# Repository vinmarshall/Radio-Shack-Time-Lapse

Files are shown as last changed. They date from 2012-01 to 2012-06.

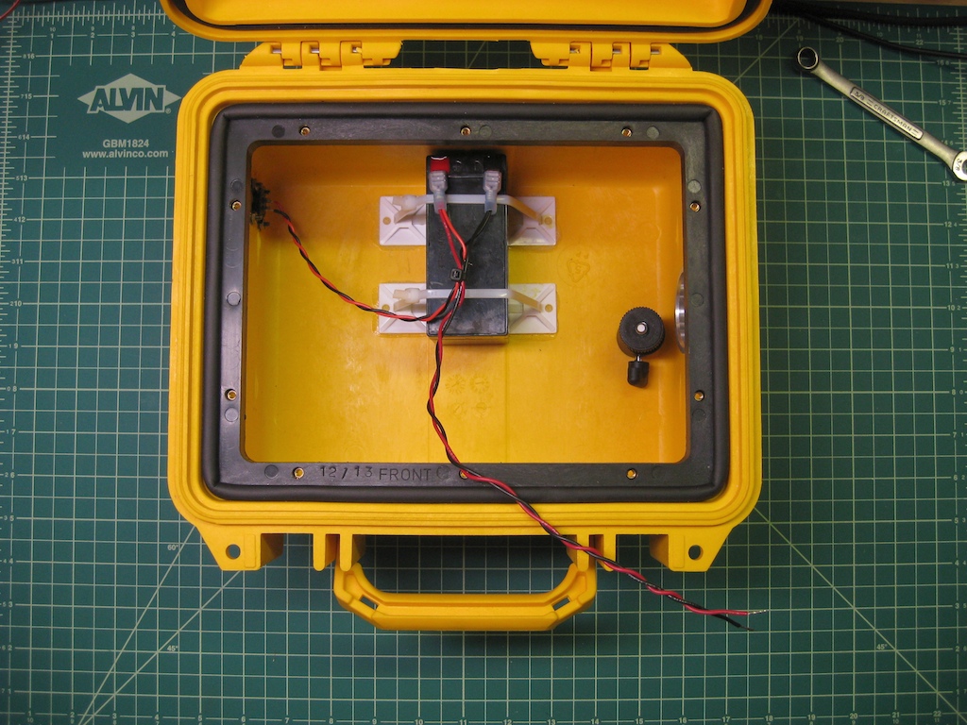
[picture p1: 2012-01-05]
images/wiring/battery_1.jpg

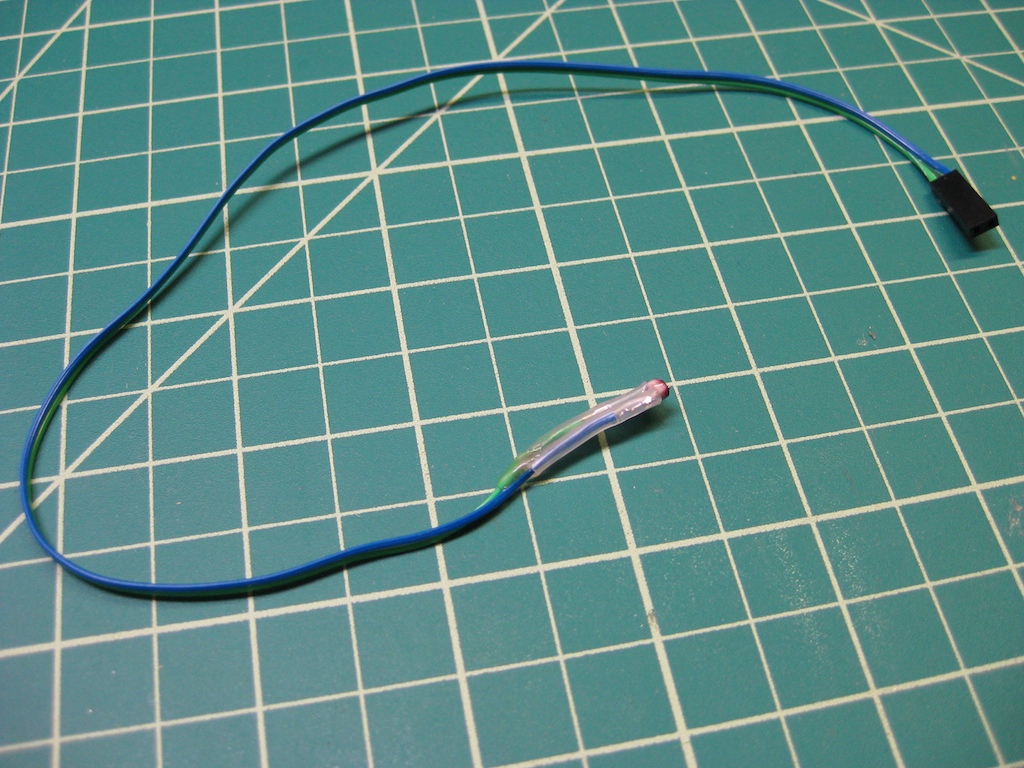
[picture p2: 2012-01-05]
images/wiring/daylight_sensor_1.jpg

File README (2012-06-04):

These files are the plans for the "Rugged Outdoor Time Lapse" project
that was featured in the September 2011 issue of Popular Science.  Look 
at the instructions file for more information.

./front_panel - Files for making the control panel.

./images - Pictures of details of building the project.

./PCB - Circuit schematic and board layout.  Express PCB files plus
  images of the trace layers and mechanical drawings of the board.

./parts - Bill of Materials and parts sourcing information

./schematic - The schematic for the circuit

./time_lapse_code - Arduino code

instructions - Instructions for building this project

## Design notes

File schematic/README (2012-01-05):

The files in this directory are images of the schematic.  This information
is the same as the PCB/rs_time_lapse.sch file, presented here as a series
of images.

Each images corresponds to one sheet in the schematic.

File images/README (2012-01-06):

This directory contains Images with the details of the various stages of 
bulding this project.  They are referenced from the instructions.

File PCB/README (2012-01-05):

The files in this directory pertain to the printed circuit board design.

The .sch and .pcb files are in the ExpressPCB file format.  You can also purchase
a board from me (vlm@2552.com).

Even if you don't choose to have your board professionally made, the mechanical
drawings, pictures of component placement, and the PDFs of the board layers
are in this directory.

PCBComponents_Custom/ - custom ExpressPCB components for this project

SchComponents_Custom/ - custom ExpressPCB schematic symbols for this project

pcb_bottom_traces.pdf - Traces on the bottom side of the board

pcb_components.bmp - Component placement and silkscreen

pcb_mechanical.AD_DRW - This PCB as an Alibre Design 3D part

pcb_mechanical.dxf - DXF of this PCB

pcb_mechanical.pdf - PDF of the PCB with dimensions

pcb_silkscreen.pdf - The silkscreen layer

pcb_top_traces.pdf - Traces on the top side of the board

rs_time_lapse.pcb - PCB in ExpressPCB file format

rs_time_lapse.sch - Schematic in ExpressPCB file format

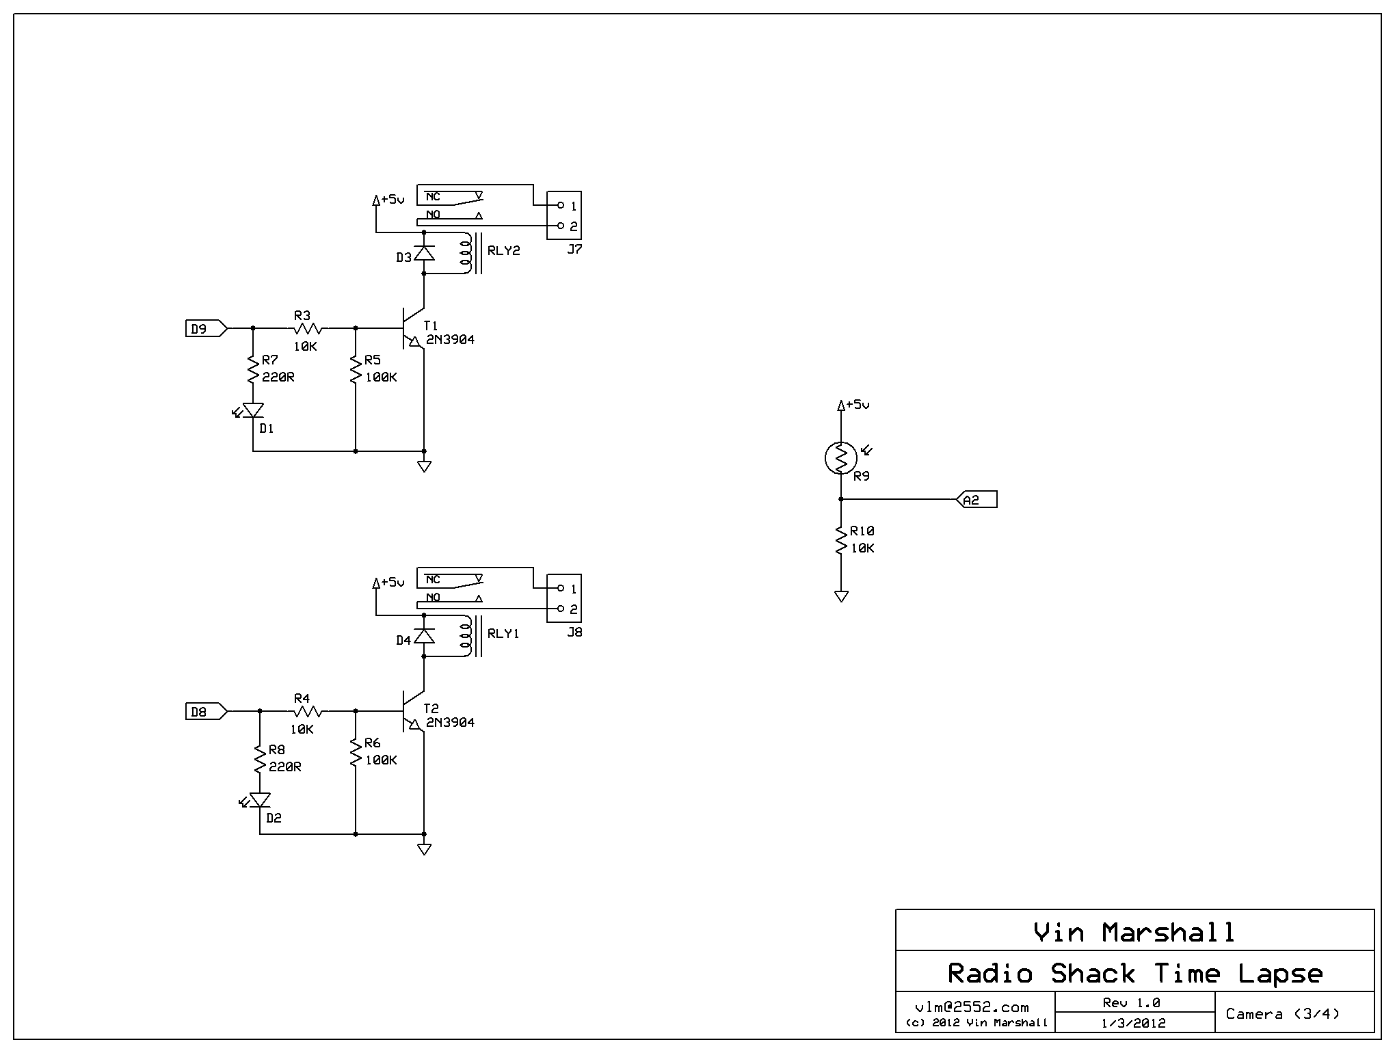
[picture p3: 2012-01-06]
schematic/3_camera.bmp

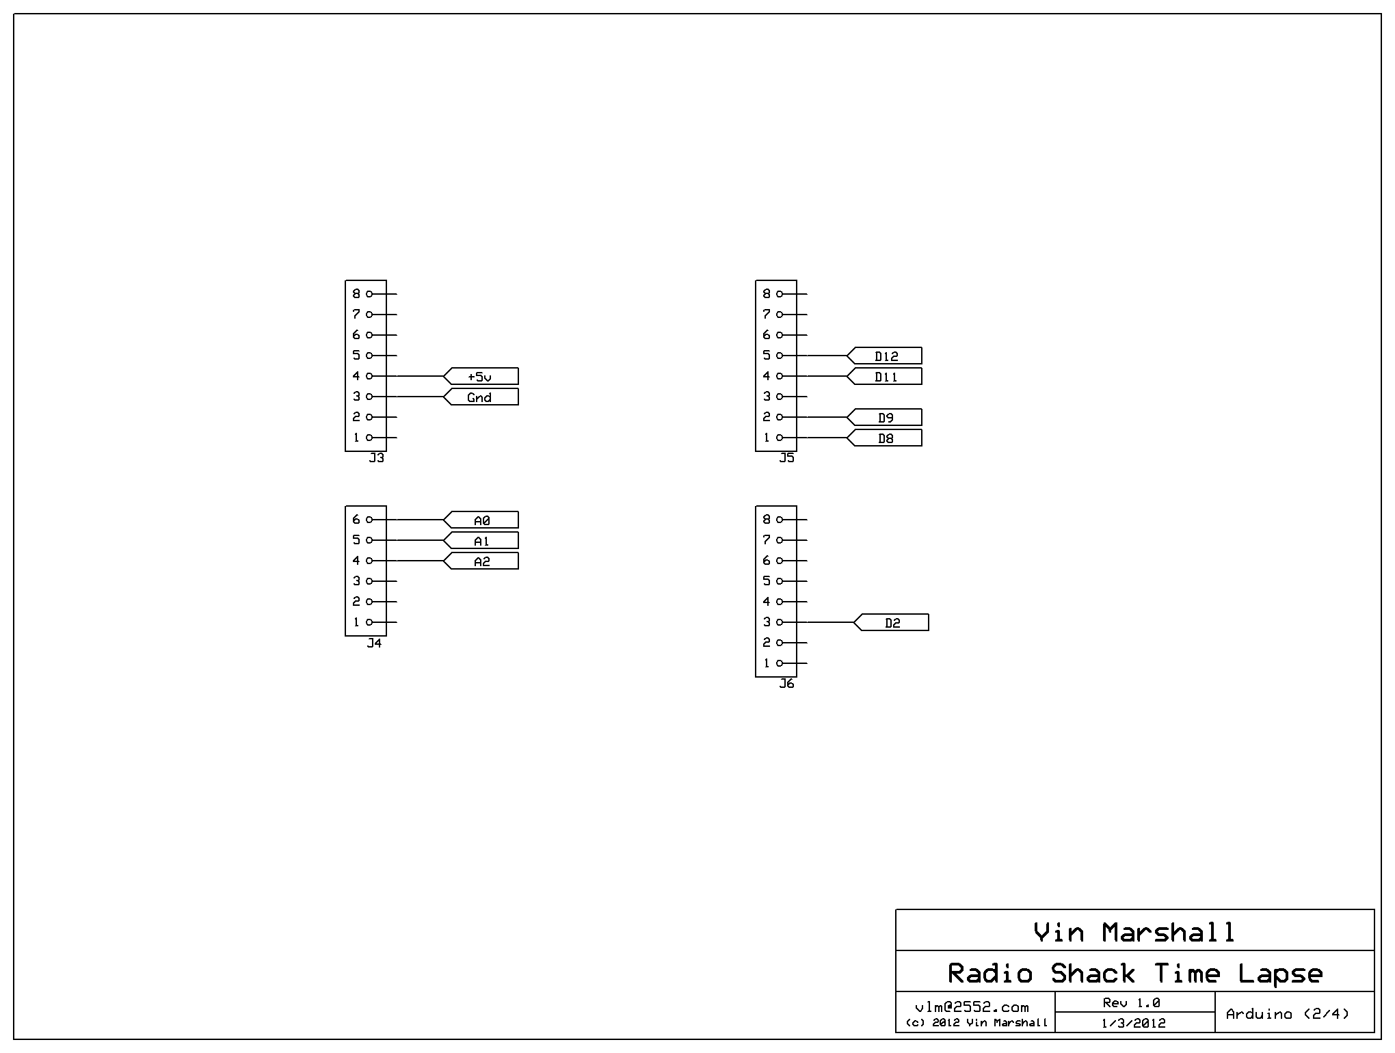
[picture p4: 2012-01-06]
schematic/2_arduino_connections.bmp

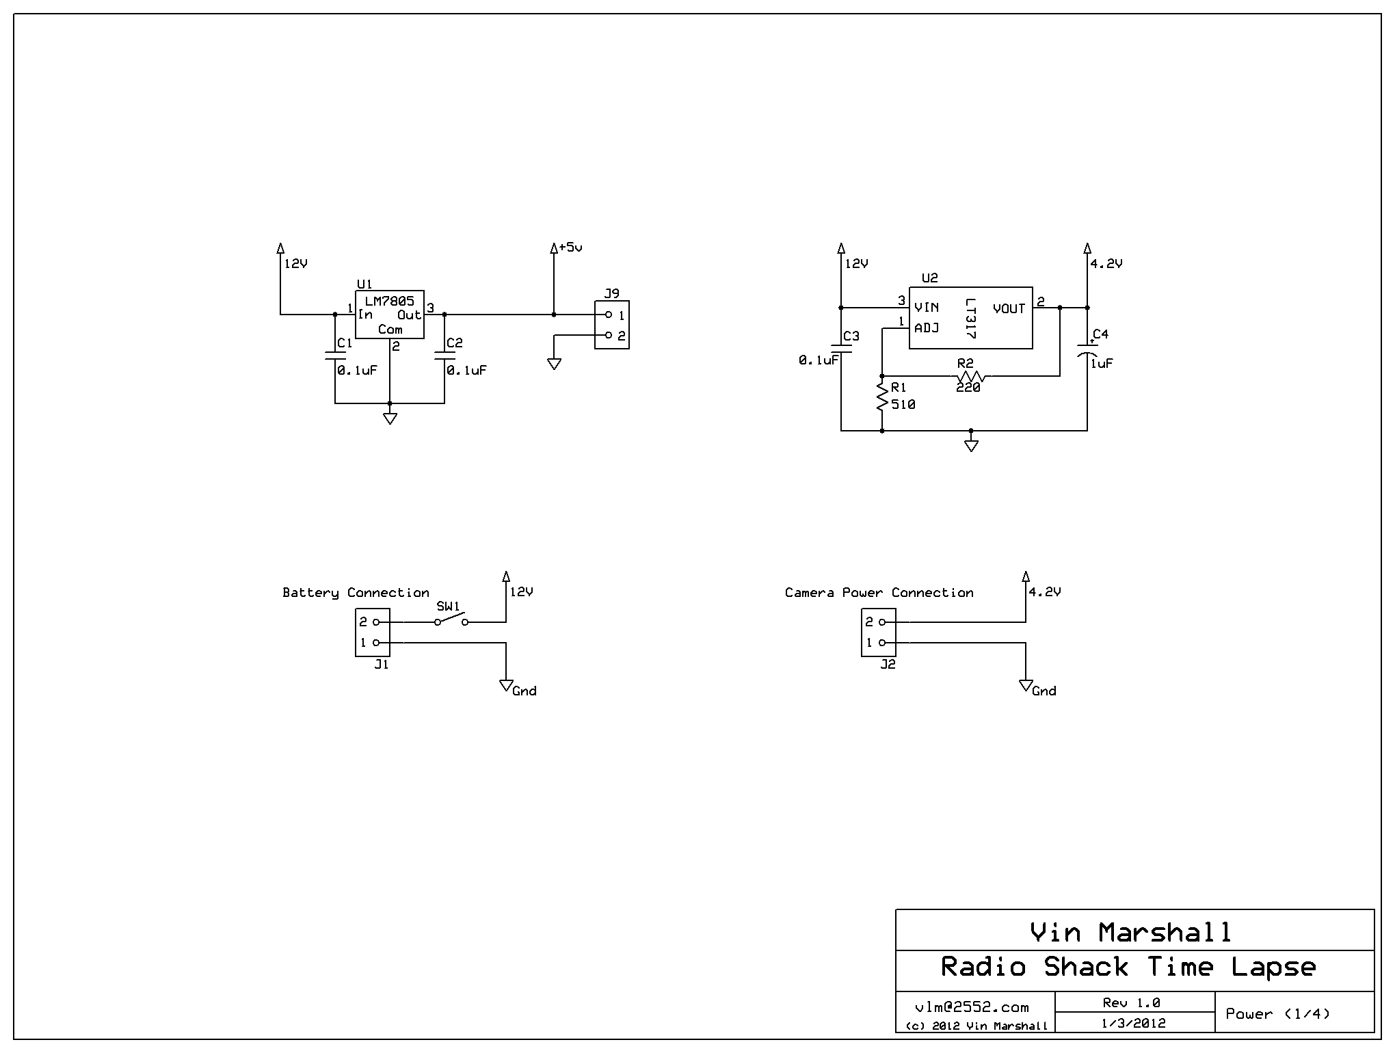
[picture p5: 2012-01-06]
schematic/1_power.bmp

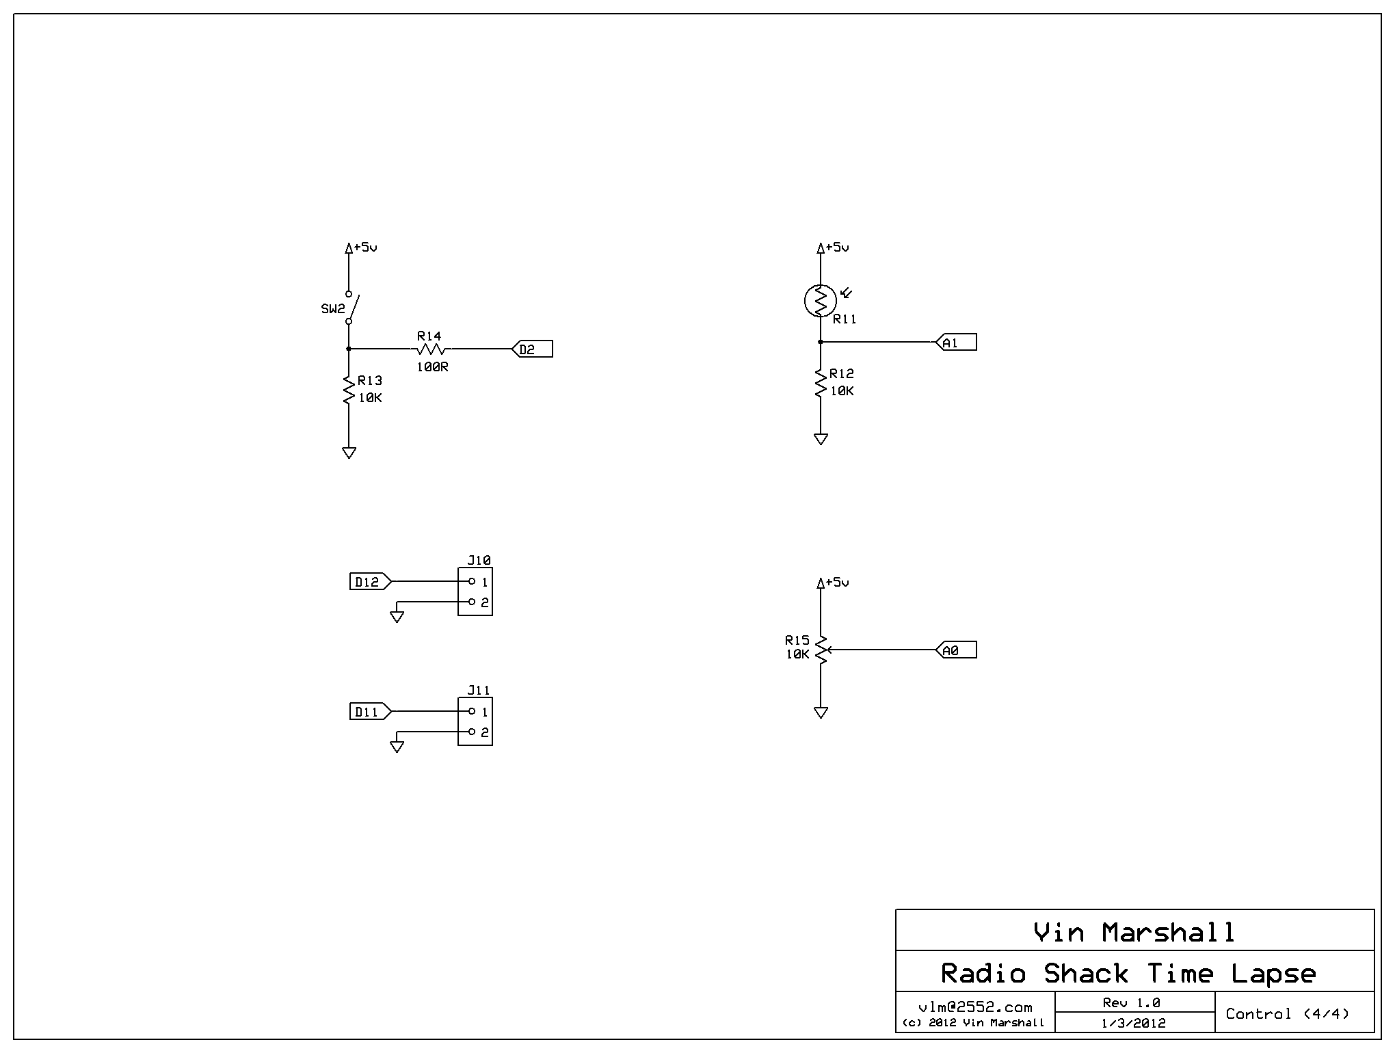
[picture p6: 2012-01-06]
schematic/4_control.bmp

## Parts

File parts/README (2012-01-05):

The files in this directory contain information on sourcing parts for this 
project.

circuit_board_BOM - A chart correlating part numbers on the schematic and 
  PCB to actual parts.

ordering_BOM - A Bill of Materials for ordering parts for this project.

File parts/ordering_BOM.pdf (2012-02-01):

Sheet1

### Outdoor Time Lapse – Bill Of Materials

Version 1.0

Check for the most recent version of this file at:

Quantity Part | Vendor | Part Number
2 | 0.1uF Capacitor | Radio Shack | 272-0135
1 | 1uF Capacitor | Radio Shack | 272-0996
1 | Red LED | Radio Shack | 276-0041
1 | 1N4004 Diode | Radio Shack | 276-1103
1 | Screw Terminals | Radio Shack | 276-1388
1 | 1/4W Resistor Assortment | Radio Shack | 271-312
1 | | Radio Shack | 276-1657
1 | 10K Potentiometer | Radio Shack | 271-1715
1 | Control Knob | Radio Shack | 274-018
2 | 5VDC Reed Relay | Radio Shack | 275-0232
2 | SPST Toggle Switch | Radio Shack | 275-634
1 | Red LED Assembly | Radio Shack | 276-0270
1 | Green LED Assembly | Radio Shack | 276-0271
1 | Yellow LED Assembly | Radio Shack | 276-0272
2 | 2N3904 Transistor | Radio Shack | 276-2016
1 | LM7805 Voltage Regulator | Radio Shack | 276-1770
1 | LT317 Voltage Regulator | Radio Shack | 276-1778
1 | Canon PowerShot A3300 Camera | Radio Shack | 16-1920
1 | 32 GB SDHC Memory Card | Radio Shack | 55041523
1 | | Radio Shack | 55038529
1 | 12V 1.3 Ah Battery | Radio Shack | 23-9080
1 | Wire-Tie Mounts | Radio Shack | 278-441
2 | Heat Sink | Radio Shack | 276-1363
2 | Heat Sink Mounting Kit | Radio Shack | 276-1373
1 | 0.1” Headers | | PRT-00116
9 | 2 Pin Jumper Wire | | PRT-10372
1 | 3 Pin Jumper Wire | | PRT-10373
1 | Case – Yellow, No Foam | Pelican | 1300
1 | Control Panel Mount | Pelican | 1200/1300 Panel Frame
1 | Control Panel | Front Panel Express | N/A
1 | 17” Cable Ties | McMaster Carr | 7130K21
1 | Porthole Window | McMaster Carr | 1116K24
1 | MIL Spec weatherproof plug | McMaster Carr | 8903T21
1 | MIL Spec weatherproof socket | McMaster Carr | 8903T31
1 | #4-40 x 3/8” Nylon Standoffs | McMaster Carr | 92745A321
1 | #4-40 Nylon Nuts | McMaster Carr | 94812A112
1 | #4-40 x 3/16” Nylon Pan Head Screws McMaster Carr | 93135A105
1 | #6-32 x 1.5” AL Standoffs | McMaster Carr | 91780A337
1 | #6-32 Nuts | McMaster Carr | 91841A007
1 | #6-32 x 3/16” Pan Head Screws | | 91772A143
1 | 3/8”-16 Flat Head Screw | McMaster Carr | 91771A622
1 | Mini Ball Head Camera Mount | | MH-1004
1 | Canon AC Power Adapter | Canon | ACK-DC60

https://github.com/vinmarshall/Radio-Shack-Time-Lapse

Photoresistor Assortment

Sunforce 5W Solar Panel

Sparkfun Electronics
Sparkfun Electronics
Sparkfun Electronics

Mcmaster Carr

Gittos

1 | SD Card Extension | | SD2C
1 | Printed Circuit Board | Vin Marshall | N/A
| | Beatsonic

Source
www.radioshack.com
www.radioshack.com
www.radioshack.com
www.radioshack.com
www.radioshack.com
www.radioshack.com
www.radioshack.com
www.radioshack.com
www.radioshack.com
www.radioshack.com
www.radioshack.com
www.radioshack.com
www.radioshack.com
www.radioshack.com
www.radioshack.com
www.radioshack.com
www.radioshack.com
www.radioshack.com
www.radioshack.com
www.radioshack.com
www.radioshack.com
www.radioshack.com
www.radioshack.com
www.radioshack.com
www.sparkfun.com
www.sparkfun.com
www.sparkfun.com
www.caseclub.com
www.caseclub.com
www.frontpanelexpress.com
www.mcmaster.com
www.mcmaster.com
www.mcmaster.com
www.mcmaster.com
www.mcmaster.com
www.mcmaster.com
www.mcmaster.com
www.mcmaster.com
www.mcmaster.com
www.mcmaster.com
www.mcmaster.com
www.bhphotovideo.com
www.buy.com Or www.bhphotovideo.com

sam@beatsonicusa.com
Vlm@2552.com

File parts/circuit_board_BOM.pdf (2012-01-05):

Sheet1

### Outdoor Time Lapse – Circuit Board Bill Of Materials

Version 1.0

Check for the most recent version of this file at:

D1 | Red LED | Radio Shack 276-0041
D2 | Red LED | Radio Shack 276-0041
D3 | 1N4004 | Radio Shack 276-1103
D4 | 1N4004 | Radio Shack 276-1103
J1 | Battery Connection | Radio Shack 276-1388
J2 | Camera Power Connection Radio Shack 276-1388
J3
J4
J5
J6
J7 | Power Button Header
J8 | Shutter Button Header
J9 | Power LED Header
J10 | Sunlight LED Header
J11 | Status LED Header
R1 | 510 | Radio Shack 271-312
R2 | 220 | Radio Shack 271-312
R3 | 10K | Radio Shack 271-312
R4 | 10K | Radio Shack 271-312
R5 | 100K | Radio Shack 271-312
R6 | 100K | Radio Shack 271-312
R7 | 220R | Radio Shack 271-312
R8 | 220R | Radio Shack 271-312
R9 | | Radio Shack 276-1657
R10 | 10K | Radio Shack 271-312
R11 | | Radio Shack 276-1657
R12 | 10K | Radio Shack 271-312
R13 | 10K | Radio Shack 271-312
R14 | 100R | Radio Shack 271-312
R15 | 10K | Radio Shack 271-1715
RLY1 | 5VDC Reed Relay | Radio Shack 275-0232
RLY2 | 5VDC Reed Relay | Radio Shack 275-0232
SW1 | SPST Toggle | Radio Shack 275-634
SW2 | SPST Toggle | Radio Shack 275-634
T1 | 2N3904 | Radio Shack 276-2016
T2 | 2N3904 | Radio Shack 276-2016
U1 | LM7805 | Radio Shack 276-1770
U2 | LT317 | Radio Shack 276-1778

https://github.com/vinmarshall/Radio-Shack-Time-Lapse

Arduino Power Header | Sparkfun PRT-00116
Arduino Analog Header | Sparkfun PRT-00116
Arduino Digital Header 2 | Sparkfun PRT-00116
Arduino Digital Header 1 | Sparkfun PRT-00116
| Sparkfun PRT-00116
| Sparkfun PRT-00116
| Sparkfun PRT-00116
| Sparkfun PRT-00116
| Sparkfun PRT-00116

Photoresistor

Photoresistor

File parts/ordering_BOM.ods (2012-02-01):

Outdoor Time Lapse – Bill Of Materials
Version 1.0
Check for the most recent version of this file at:
https://github.com/vinmarshall/Radio-Shack-Time-Lapse
Quantity | Part | Vendor | Part Number | Source
2 | 0.1uF Capacitor | Radio Shack | 272-0135 | www.radioshack.com
1 | 1uF Capacitor | Radio Shack | 272-0996 | www.radioshack.com
1 | Red LED | Radio Shack | 276-0041 | www.radioshack.com
1 | 1N4004 Diode | Radio Shack | 276-1103 | www.radioshack.com
1 | Screw Terminals | Radio Shack | 276-1388 | www.radioshack.com
1 | 1/4W Resistor Assortment | Radio Shack | 271-312 | www.radioshack.com
1 | Photoresistor Assortment | Radio Shack | 276-1657 | www.radioshack.com
1 | 10K Potentiometer | Radio Shack | 271-1715 | www.radioshack.com
1 | Control Knob | Radio Shack | 274-018 | www.radioshack.com
2 | 5VDC Reed Relay | Radio Shack | 275-0232 | www.radioshack.com
2 | SPST Toggle Switch | Radio Shack | 275-634 | www.radioshack.com
1 | Red LED Assembly | Radio Shack | 276-0270 | www.radioshack.com
1 | Green LED Assembly | Radio Shack | 276-0271 | www.radioshack.com
1 | Yellow LED Assembly | Radio Shack | 276-0272 | www.radioshack.com
2 | 2N3904 Transistor | Radio Shack | 276-2016 | www.radioshack.com
1 | LM7805 Voltage Regulator | Radio Shack | 276-1770 | www.radioshack.com
1 | LT317 Voltage Regulator | Radio Shack | 276-1778 | www.radioshack.com
1 | Canon PowerShot A3300 Camera | Radio Shack | 16-1920 | www.radioshack.com
1 | 32 GB SDHC Memory Card | Radio Shack | 55041523 | www.radioshack.com
1 | Sunforce 5W Solar Panel | Radio Shack | 55038529 | www.radioshack.com
1 | 12V 1.3 Ah Battery | Radio Shack | 23-9080 | www.radioshack.com
1 | Wire-Tie Mounts | Radio Shack | 278-441 | www.radioshack.com
2 | Heat Sink | Radio Shack | 276-1363 | www.radioshack.com
2 | Heat Sink Mounting Kit | Radio Shack | 276-1373 | www.radioshack.com
1 | 0.1” Headers | Sparkfun Electronics | PRT-00116 | www.sparkfun.com
9 | 2 Pin Jumper Wire | Sparkfun Electronics | PRT-10372 | www.sparkfun.com
1 | 3 Pin Jumper Wire | Sparkfun Electronics | PRT-10373 | www.sparkfun.com
1 | Case – Yellow, No Foam | Pelican | 1300 | www.caseclub.com
1 | Control Panel Mount | Pelican | 1200/1300 Panel Frame | www.caseclub.com
1 | Control Panel | Front Panel Express | N/A | www.frontpanelexpress.com
1 | 17” Cable Ties | McMaster Carr | 7130K21 | www.mcmaster.com
1 | Porthole Window | McMaster Carr | 1116K24 | www.mcmaster.com
1 | MIL Spec weatherproof plug | McMaster Carr | 8903T21 | www.mcmaster.com
1 | MIL Spec weatherproof socket | McMaster Carr | 8903T31 | www.mcmaster.com
1 | #4-40 x 3/8” Nylon Standoffs | McMaster Carr | 92745A321 | www.mcmaster.com
1 | #4-40 Nylon Nuts | McMaster Carr | 94812A112 | www.mcmaster.com
1 | #4-40 x 3/16” Nylon Pan Head Screws | McMaster Carr | 93135A105 | www.mcmaster.com
1 | #6-32 x 1.5” AL Standoffs | McMaster Carr | 91780A337 | www.mcmaster.com
1 | #6-32 Nuts | McMaster Carr | 91841A007 | www.mcmaster.com
1 | #6-32 x 3/16” Pan Head Screws | Mcmaster Carr | 91772A143 | www.mcmaster.com
1 | 3/8”-16 Flat Head Screw | McMaster Carr | 91771A622 | www.mcmaster.com
1 | Mini Ball Head Camera Mount | Gittos | MH-1004 | www.bhphotovideo.com
1 | Canon AC Power Adapter | Canon | ACK-DC60 | www.buy.com Or www.bhphotovideo.com
1 | SD Card Extension | Beatsonic | SD2C | sam@beatsonicusa.com
1 | Printed Circuit Board | Vin Marshall | N/A | Vlm@2552.com

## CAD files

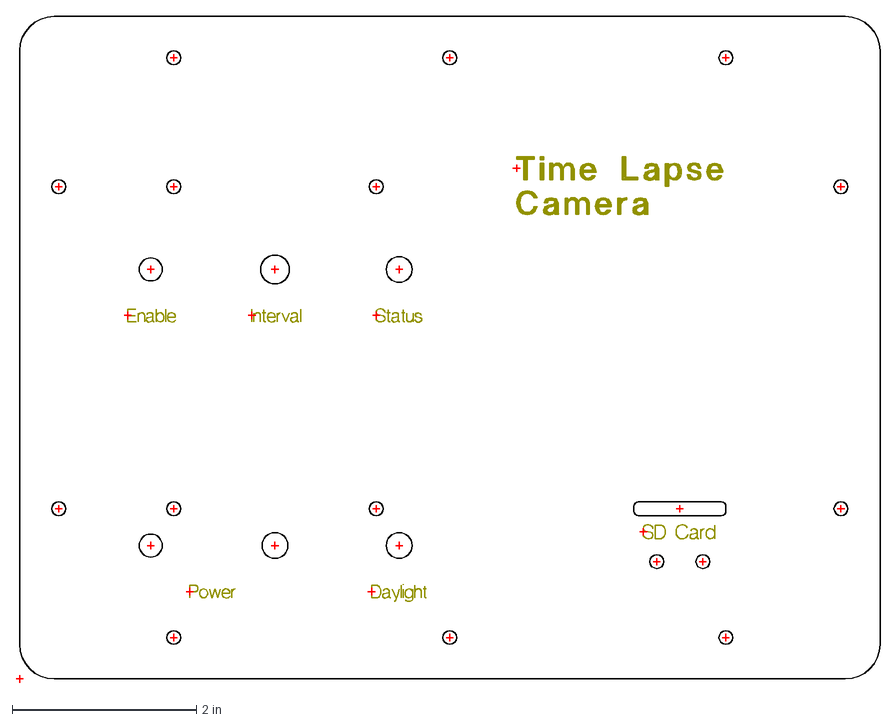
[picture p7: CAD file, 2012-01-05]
front_panel/rs_time_lapse.dxf
9.39 x 7.24 in

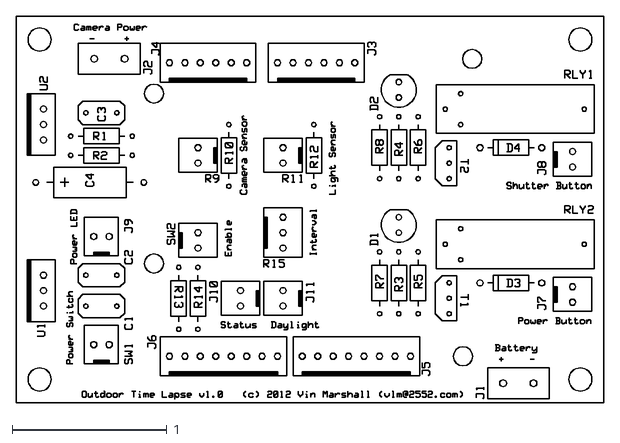
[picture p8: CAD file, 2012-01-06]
PCB/pcb_mechanical.dxf
3.80 x 2.50

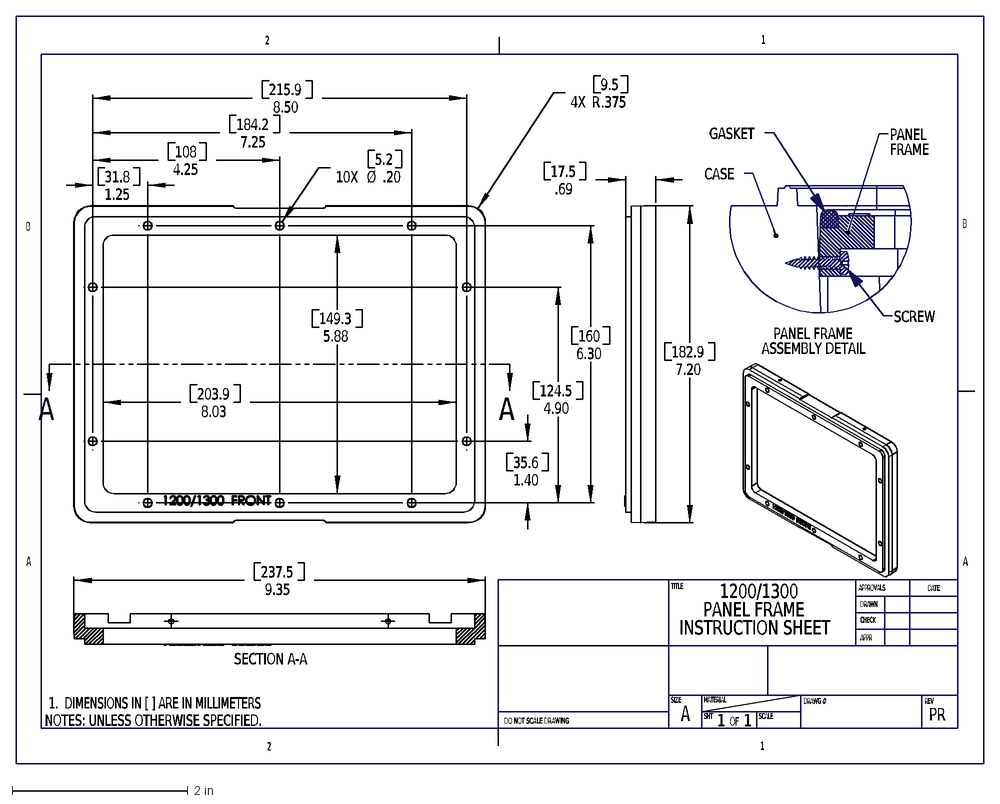
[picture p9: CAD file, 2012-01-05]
front_panel/1300 PANEL FRAME_OEM.DXF
NOTES: UNLESS OTHERWISE SPECIFIED.
1. DIMENSIONS IN [ ] ARE IN MILLIMETERS
SCREW
PANEL FRAME
ASSEMBLY DETAIL
CASE
PANEL
FRAME
GASKET
DO NOT SCALE DRAWING
A
TITLE
DATE
DRAWN
CHECK
APPROVALS
REV
DRAWG #
MATERIAL
SHT
SCALE
SIZE
OF
1
1200/1300
INSTRUCTION SHEET
APPR
B
2
PR
1.25
31.8
4.25
108
7.25
184.2
8.50
215.9
1.40
35.6
4.90
124.5
6.30
160
5.88
149.3
8.03
203.9
10X
Ø
.20
5.2
4X
R
.375
9.5
7.20
182.9
.69
17.5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

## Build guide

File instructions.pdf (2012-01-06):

### Rugged Outdoor Time Lapse

Vin Marshall (vlm@2552.com)
Version 1.0

Check for the most recent version of this file at: https://github.com/vinmarshall/Radio-Shack-Time-Lapse

Instructions:

1. Source Parts

Before you start, you'll need to gather all of the parts needed to build the project. Everything you will need is listed in the ./parts/ordering_BOM file along with the sources.

You may want to outsource the control panel and the printed circuit board. Information about sources for those parts is in the relevant step of the instructions.

2. Circuit Board

The printed circuit board layout for this project can be found in the ./PCB directory.

You can order this PCB from ExpressPCB (www.expresspcb.com – 3 for $75 or $51, with or without the silkscreen and soldermask), or from me (vlm@2552.com - $30 with silkscreen and soldermask).

If you'd like to make the circuit board yourself, you can etch one on your own – with just a couple of wire jumpers on the top side, this could be a one sided layout – or you can do point to point wiring. I designed the PCB to have the same mounting hole pattern as Radio Shack p/n 276-168.

However you choose to make the circuit board, you'll use the ./parts/circuit_board_BOM and the ./PCB/pcb_components.bmp files to locate components on the board.

Solder everything in place, being careful to avoid solder bridges and cold joints. Attach heat sinks to the two voltage regulator ICs.

Test the board in the next step, after connecting the front panel controls.

3. Front Panel

The ./front_panel/rs_time_lapse.fpd file is a panel you can order from Front Panel Express (www.frontpanelexpress.com). A DXF of the panel dimensions is also included in that directory if you'd like to make it yourself or take it to a local shop.

The controls and indicators in the front panel need to have leads attached that will connect them to the circuit board. Refer to the pictures in ./images/panel and pay attention to the position of the leads in the plastic connector body. You will be aligning pin #1 of these connectors (see the arrow in

./images/panel/jumper.jpg) with the corresponding header pin #1 on the circuit board (see the square pads in ./images/panel/pins.jpg).

Test the voltage regulation section of the circuit at this point. Connect the power switch and the power indicator LED from the front panel to the circuit board. Then connect the battery. Pay attention to the correct polarity when making the battery and LED connections. Using a multimeter, verify that regulator U1 is putting out 5V and regulator U2 is putting out 4.2V.

4. Arduino

If you don't already have it, download the Arduino software from http://www.arduino.cc/.

Open the Arduino software and connect the Arduino to your computer via USB. Under the “Tools” drop down menu, select your board type (Arduino UNO for this project) and serial port (/dev/tty.usbmodem***). Open the time_lapse_code.pde file and download the program to the Arduino.

If you have any problems with connecting and programming the Arduino, consult the help available in the Arduino forums at http://arduino.cc/forum/.

Once the Arduino has been successfully programmed, disconnect it from the computer and attach it to the circuit board using the #4-40 nylon standoffs with the USB port facing away from the voltage regulator ICs. Arduino headers connect to the J3, J4, J5, and J6 header pins on the circuit board.

5. Attach The Circuit Board

The circuit board attaches to the back of the control panel with four long #6-32 hex standoffs and eight #6-32 machine screws. Mount the circuit board so that the Arduino is toward the control panel and the components on the PCB are pointing away.

Connect all of the jumpers from the front panel LEDs and controls to the headers on the PCB. The ./PCB/components.bmp image shows where to connect each lead. Align pin #1 on the jumpers (arrow) with pin #1 on the circuit board (square pad).

6. Prepare The Pelican Case

The camera, battery, solar panel port, porthole window, and a support for the control panel have to be mounted in the pelican case.

To install the “panel frame” that supports the control panel, follow the instructions that came with it.

Refer to the pictures in ./images/pelican for mounting the rest of the components. The exact placement is not crucial, other than ensuring that the camera lines up with the porthole when it has the lens out. That clearance is tight and you'll have to pay attention to getting it right or the porthole will interfere with the lens opening.

Seal the mounting holes with RTV except for the big one for the porthole, which comes with it's own gasket. Use 3M DP-8010 epoxy to attach the hold downs for the battery. Let the epoxy cure for at least 8 hours before installing the battery.

7. Other Wiring

Use the pictures in ./images/wiring to wire the solar power and battery connections and the daylight sensing photocell. Polarity matters for the battery connections. Use the smallest photoresistor in the Radio Shack assortment. Glue it into place in the porthole such that it will not interfere with the opening of the camera lens.

8. Mount the SD Card Extension

Bend a scrap of aluminum or cut a section of aluminum angle to make a mounting tab for the extended SD card socket. Glue the SD card socket onto this tab.

Then position the socket so that the SD card fits through the slot in the front panel and transfer the mounting holes from the front panel onto the SD card socket's mounting tab. Drill the holes and mount the SD card socket to the front panel.

9. Modify The Camera

The camera needs to be modified so that the Arduino can take control of the power and shutter buttons. Modifying the camera is, by far, the most difficult part of this project. You will probably first want to practice this procedure a few times on cameras that you didn't just spend over $100 on. You can easily destroy the camera with this step if you are not careful.

WARNING:

While working with the camera, be extremely careful not to shock yourself with the flash capacitor. It hurts. Especially the second time.

Avoid contact with any leads or wiring connected to the large capacitor in the front right of the camera. Some of it's wiring is close to the power and shutter buttons that you will be modifying. Identify where these leads are before you start the modifications.

Refer to the pictures in ./images/camera for details on this process:
1. Remove the 4 external screws.
2. Carefully pry off the back cover.
3. Carefully pry off the front cover. It flips up, with a tab between the power and shutter buttons retaining it.
4. Pop off the cover holding the shutter and power buttons and remove those buttons to create openings for the wires to pass through. Drill a hole through where the shutter button was to create extra clearance.
5. Cut the end off of a 2 wire jumper, strip and tin the wires, and solder it on top of the (very small) leads for the power button. Refer to the pictures for which leads to piggyback on. Visually inspect this through a magnifying glass to make sure that you didn't bridge the solder onto another trace or onto the body of the original switch. Test the camera after doing this. With a battery in the camera, you should now be able turn the camera on by briefly shorting the two wires in the jumper together. Go back and try again if it didn't work.
6. Repeat step 5 for the shutter button. Refer to the pictures.
7. Fix the leads in hot glue or epoxy to keep them from getting pulled off of their connections. When potting these leads, keep in mind where the cover will fit and how little space is available.
8. Fish the jumpers through their respective holes in the plastic button cover that you removed in
step 4 and reinstall it.
9. Reverse steps 1 through 3 to put the camera back together. Verify that the camera still works by turning on the power and shooting a picture using the new leads. Go back and try again if it doesn't.
10. Attach a jumper to a photoresistor as you did for the daylight sensor and glue that sensor to the screen on the back of the camera.
11. Use a cable clamp to secure all of the leads.
12. Replace the camera battery with the battery adapter from the AC power kit.
10. Put It All Together

Put the camera on the mount, making sure the lens still clears the porthole. Plug in the SD card extension cable and the power cable. Plug the 3 sets of leads from the camera onto their respective headers on the circuit board.

Turn the power switch off. Connect the leads from the battery to the screw terminals (J1) on the circuit board. Take a minute to double check all of your wiring.

Install the front panel into the Pelican case.

Turn the enable switch off. Set the interval knob all the way to the right. Cross fingers. Turn the power switch on. The power light should come on. If you are in daylight or a bright room, the “daylight” light on the panel should also come on. If it isn't on, make sure there is sufficient ambient light.

With the power and daylight lights on, flip the enable switch to on. After about 5 seconds, the green status light should come on and remain on for about 5 seconds while the camera powers up and shoots a picture.

You can adjust the range of the available time intervals. See the Arduino code for more details.

11. Operating Instructions

The interval between pictures is set by the interval knob on the front panel. Turning the knob to the right takes pictures more frequently. The time lapse will not shoot pictures unless there is daylight and

the enable switch is on.

Insert an SD card before turning on the camera. When you need to change SD cards, turn the enable switch off and wait for the camera to power down. You can verify this by looking through the porthole to confirm that the lens is retracted. After swapping SD cards, you can turn the enable switch back on and operation will resume as normal.

Turn the enable switch off and allow the camera to power down before turning off the main power switch.

Copyright 2012 Vin Marshall (vlm@2552.com)

DISCLAIMER: This project is not a consumer product; it is just one hobbyist sharing his plans. It is provided "AS IS" without warranty of any kind, either expressed or implied, including, but not limited to the implied warranties of merchantability and fitness for a particular purpose. You are building and operating this at your own risk.

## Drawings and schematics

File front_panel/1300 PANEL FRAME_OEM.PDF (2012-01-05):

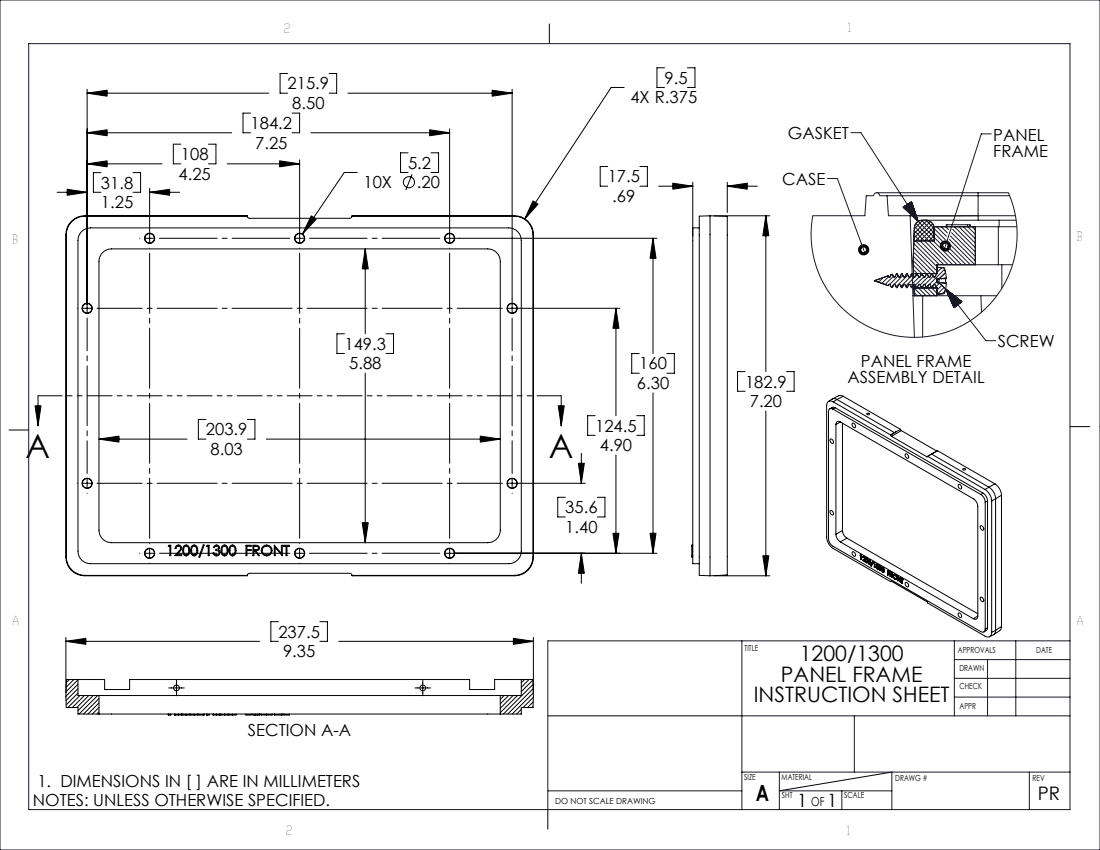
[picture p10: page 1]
SECTION A-A; PANEL FRAME ASSEMBLY DETAIL; DO NOT SCALE DRAWING; MATERIAL; DRAWG #; REV

PANEL FRAME
INSTRUCTION SHEET APPR

1. DIMENSIONS IN [ ] ARE IN MILLIMETERS
NOTES: UNLESS OTHERWISE SPECIFIED.

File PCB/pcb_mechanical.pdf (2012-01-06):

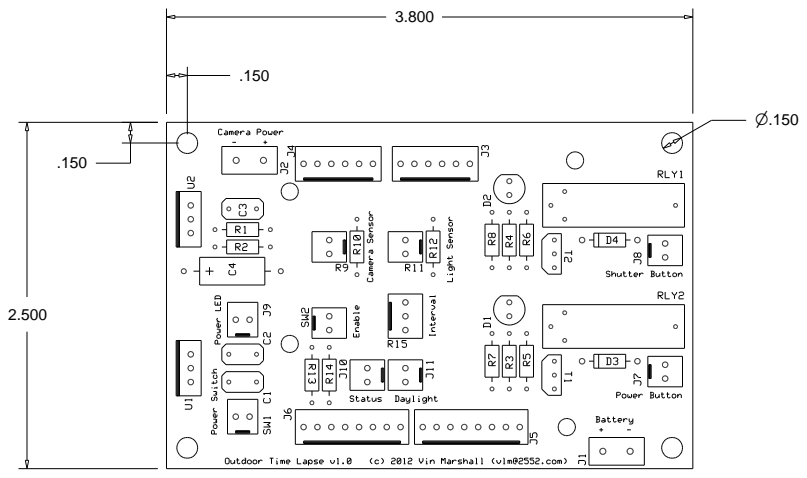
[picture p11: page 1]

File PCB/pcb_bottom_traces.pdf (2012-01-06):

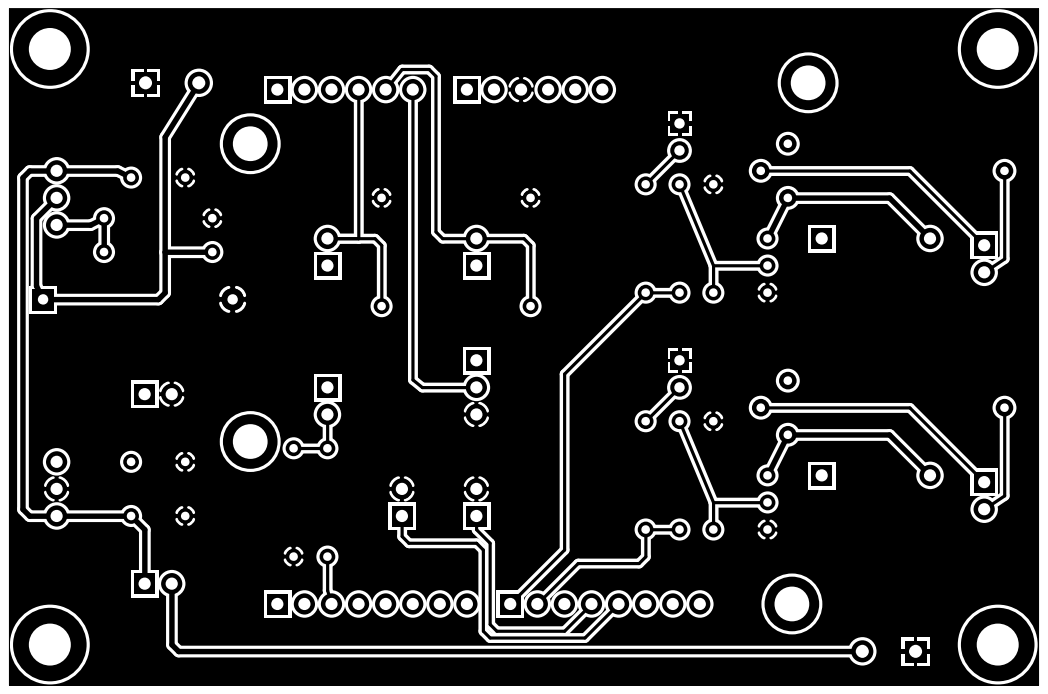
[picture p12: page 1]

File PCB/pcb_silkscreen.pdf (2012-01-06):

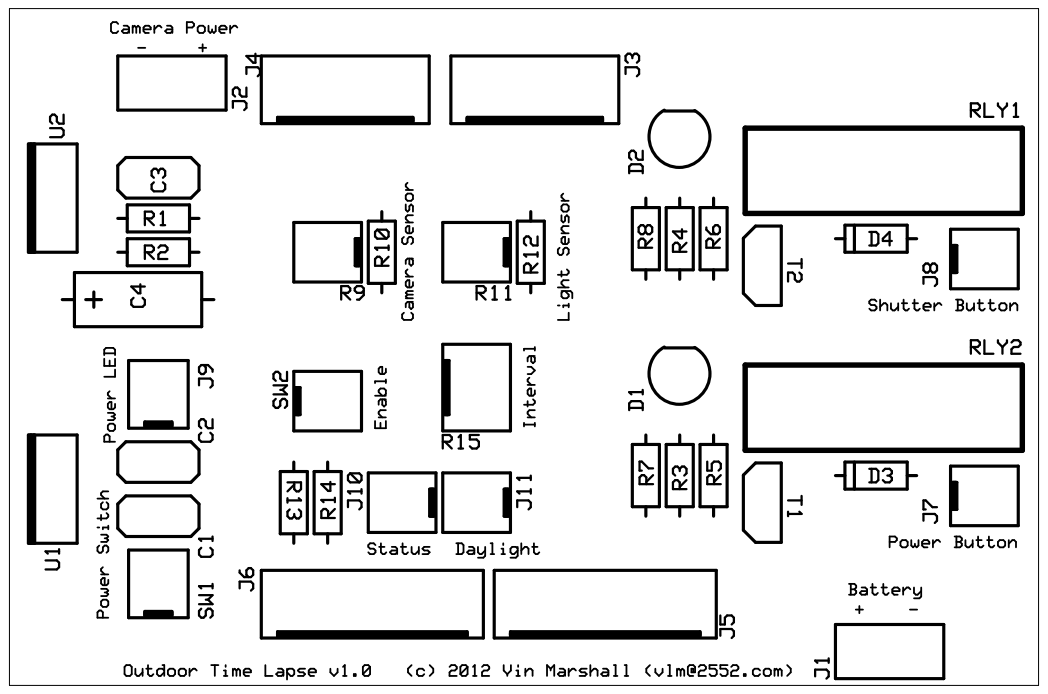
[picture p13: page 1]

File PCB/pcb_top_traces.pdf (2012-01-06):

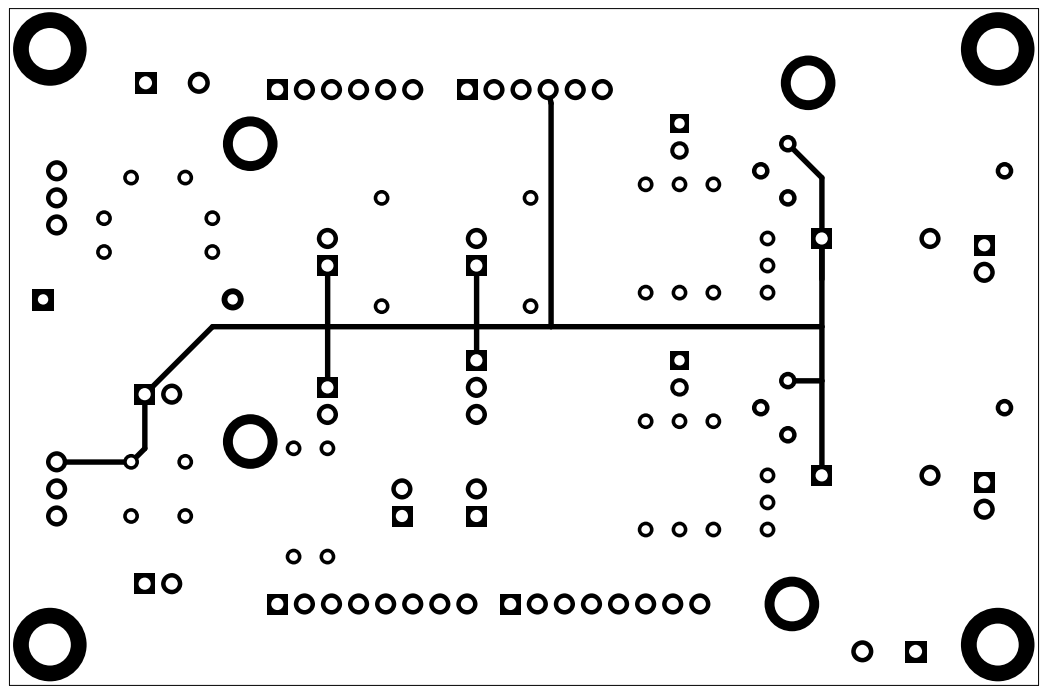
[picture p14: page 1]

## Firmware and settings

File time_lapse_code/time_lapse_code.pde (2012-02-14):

/*
 * Radio Shack - Rugged Outdoor Time Lapse 
 * Version 1.0
 *
 * This code drives a modified Canon powershot camera in a 
 * ruggedized, solar powered, very long term time lapse setup.
 *
 * Check the repository for the most recent version of this code:
 * https://github.com/vinmarshall/Radio-Shack-Time-Lapse
 *
 * Copyright (c) 2012 Vin Marshall (vlm@2552.com, www.2552.com)
 *
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
 * THE SOFTWARE IS PROVIDED "AS IS", WITHOUT WARRANTY OF ANY KIND,
 * EXPRESS OR IMPLIED, INCLUDING BUT NOT LIMITED TO THE WARRANTIES
 * OF MERCHANTABILITY, FITNESS FOR A PARTICULAR PURPOSE AND
 * NONINFRINGEMENT. IN NO EVENT SHALL THE AUTHORS OR COPYRIGHT
 * HOLDERS BE LIABLE FOR ANY CLAIM, DAMAGES OR OTHER LIABILITY,
 * WHETHER IN AN ACTION OF CONTRACT, TORT OR OTHERWISE, ARISING
 * FROM, OUT OF OR IN CONNECTION WITH THE SOFTWARE OR THE USE OR
 * OTHER DEALINGS IN THE SOFTWARE.  
 */

#define SUNLIGHT_THRESHOLD 250
#define CAMERA_SCREEN_THRESHOLD 250 
#define WAKEUP_TIME 4000
#define SHUTOFF_TIME 120000 
#define DEBUG 1

const int enableSwPin = 2;
const int powerRelayPin = 9;
const int shutterRelayPin = 8;
const int intervalPin = A0;
const int sunlightPin= A1;
const int cameraScreenPin = A2;
const int sunlightLedPin = 12;
const int statusLedPin = 11;

bool sunlight = false;
bool enabled = false;
bool lastEnableState = 0;
bool pictureTaken = false;
unsigned long interval = 0;
unsigned long lastMillis = 0;
unsigned long lastPictureMillis = 0;
unsigned long numPictures = 0;

unsigned long debounceTime = 0;
unsigned long debounceInterval = 50;

 
void setup() {
  pinMode(enableSwPin, INPUT);
  pinMode(powerRelayPin, OUTPUT);
  pinMode(shutterRelayPin, OUTPUT);
  pinMode(sunlightLedPin, OUTPUT);
  pinMode(statusLedPin, OUTPUT);

  // Make sure our relays are off by default
  digitalWrite(powerRelayPin, LOW);
  digitalWrite(shutterRelayPin, LOW);

  if (DEBUG) {
    Serial.begin(9600);
    Serial.println("Starting...");
  }
}
 
void loop() {

  /*
   * Read the "enable" switch's state
   *
   * The enable switch is on the control panel, to the left of the 
   * timer interval pot.  It enables or disables picture taking.
   */

  bool enableReading = digitalRead(enableSwPin);
  if (enableReading != lastEnableState) {
    debounceTime = millis();
  }

  if ((millis() - debounceTime) > debounceInterval) {
    enabled = enableReading;
  }

  lastEnableState = enableReading;

  /*
   * Check for daylight
   *
   * We read the photoresistor mounted in the camera's glass portal 
   * to determine whether it is day or night outside.  You may need to 
   * adjust the constants used in this section (defined above) to get
   * a day/night cutoff point that works for you.
   */

  int sunlightReading = analogRead(sunlightPin);
  sunlight = (sunlightReading >= SUNLIGHT_THRESHOLD);
  digitalWrite(sunlightLedPin, sunlight);

  /*
   * Read the interval setting
   *
   * We are reading the "timer interval" pot on the front panel and 
   * mapping it to a number of seconds between pictures.
   */

  int intervalReading = analogRead(intervalPin) + 5;  // minimum of 5
  interval = 1000 * (unsigned long) intervalReading;  // 1 to 1 sec.


  /*
   * At the end of an interval if the sun is out and the camera is 
   * enabled, shoot a picture.
   *
   * The second line of this test handles rollovers - it ensures that
   * if there has been a rollover, then both our lastMillis + interval 
   * timer AND the millis() timer have both rolled over.
   */

  if ( (millis() > (lastMillis + interval)) &&
       ( (lastMillis + interval > lastMillis) || (millis() < lastMillis) ) ) {

    // Print debugging info 
    if (DEBUG) { 
      Serial.print("Interval Timer: ");
      printInfo(); 
    }

    // Take a picture if the camera is enabled and the sun is out
    if (enabled && sunlight) {
      digitalWrite(statusLedPin, HIGH);  // blink front panel lamp 

      // Turn the camera on if it is not already on.
      if (!isCameraOn()) {
        if (DEBUG) { Serial.println("Camera On."); }
        toggleCameraPower(); 
        delay(WAKEUP_TIME); // give camera a chance to boot up
      }
      
      // Take the picture 
      numPictures++;
      if (DEBUG) { 
        Serial.print("Taking Picture: "); 
        Serial.println(numPictures);
      }
      takePicture();
      lastPictureMillis = millis();
      pictureTaken = true;
     
      digitalWrite(statusLedPin, LOW); // unblink front panel lamp
    }

    // Record when this interval ended / when the next one starts
    lastMillis = millis(); // reset interval timer
  }

  /*
   * If the next picture won't be for a while and if the last picture was 
   * taken more than 5 seconds ago, turn the camera off.
   *
   * The pictureTaken bool tells us if a picture has been taken since 
   * the last time we thought about turning off the camera - i.e. if 
   * the camera might be on.  Using this keeps us from having to poll
   * isCameraOn() all the time, which can involve energizing the shutter
   * button relay.
   */

  if ((millis() - lastPictureMillis) > 5000) {
    if ((!enabled) || (!sunlight) || (interval > SHUTOFF_TIME)) {
      if (pictureTaken && isCameraOn()) {
        if (DEBUG) { 
          Serial.print("Camera Off:  "); 
          printInfo();
        }
        pictureTaken = false;
        toggleCameraPower();
      }
    }
  }

}

/*
 * printInfo
 *
 * Used for debugging, this prints the crucial stats.
 */
void printInfo() {
  Serial.print("[Enabled: ");
  Serial.print(enabled);
  Serial.print("  Sunlight: ");
  Serial.print(sunlight);
  Serial.print("  Interval: ");
  Serial.print(interval);
  Serial.println("]");
}

/*
 * isCameraOn
 *
 * Uses a photoresistor mounted on the screen of the camera to determine
 * if the camera is on or off.  Takes advantage of the fact that pressing
 * the shutter button when the screen is sleeping turns the screen back
 * on, but doesn't take a picture.
 */

bool isCameraOn() {
  int sensorReading = analogRead(cameraScreenPin);
  if (sensorReading > CAMERA_SCREEN_THRESHOLD) {
    return true;
  } else {
    takePicture();  // turns screen on when sleeping but doesn't take picture
    delay(WAKEUP_TIME);    // give the camera a chance to wake up
    sensorReading = analogRead(cameraScreenPin);
    return (sensorReading > CAMERA_SCREEN_THRESHOLD);
  }
}

/*
 * toggleCameraPower
 *
 * This turns on the relay connected to the leads piggybacked on the
 * power button of the camera.  This function mimics pushing the 
 * power button once.
 */

void toggleCameraPower() {
  digitalWrite(powerRelayPin, HIGH);  // relay on, "press" power button
  delay(100);                         // hold button down, let it register
  digitalWrite(powerRelayPin, LOW);   // relay off - release button
}

/*
 * takePpicture
 *
 * This turns on the relay connected to the leads piggybacked on the
 * shutter button of the camera.  This function mimics pushing the
 * shutter button once.
 */

void takePicture() {
  digitalWrite(shutterRelayPin, HIGH);  // relay on, "press" shutter button
  delay(100);                           // hold button down, let it register
  digitalWrite(shutterRelayPin, LOW);   // relay off - release button
}

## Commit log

2012-01-03 added arduino code
2012-01-04 Named relays in schematic.
    [rs_time_lapse.sch]
2012-01-04 PCB v1
2012-01-04 PCB and Schematic updates.
    [rs_time_lapse.sch]
2012-01-04 v1.0 PCB design
    [pcb_mechanical.dxf]
2012-01-04 redid PDF export of pcb layers in letter size.
2012-01-05 pelican case modification images
2012-01-05 added front panel wiring images
2012-01-05 images of wiring in the pelican case
2012-01-05 added images of the camera modifications
2012-01-05 changes to pcb
2012-01-05 Updated component names in schematic and added circuit_board_BOM files
    [circuit_board_BOM.ods, circuit_board_BOM.xls, rs_time_lapse.sch]
2012-01-05 pelican case panel frame dxf
    [1300 PANEL FRAME_OEM.DXF]
2012-01-05 start of ordering BOM
    [ordering_BOM.ods]
2012-01-05 added Ordering BOM
    [ordering_BOM.ods, ordering_BOM.xls]
2012-01-05 added version info to circuit board BOM
    [circuit_board_BOM.ods, circuit_board_BOM.xls]
2012-01-05 typo in BOM
    [ordering_BOM.ods, ordering_BOM.xls]
2012-01-05 added version number to arduino code
2012-01-05 Front Panel Express layout
    [rs_time_lapse.dxf]
2012-01-06 changed pin order on interval pot leads
2012-01-06 Added image showing pin #1 markings on circuit board and updated the instructions accordingly.
2012-01-06 Changed camera power connector to a 5mm screw terminal
    [pcb_mechanical.dxf]
2012-01-06 Added millis() rollover handling to the interval testing in the arduino code
2012-01-06 rights note in schematic
    [rs_time_lapse.sch]
2012-01-14 Updated SD Card extension cable information in the BOM
    [ordering_BOM.ods, ordering_BOM.xls]
2012-02-01 added PCB source to BOM
    [ordering_BOM.ods, ordering_BOM.xls]
2012-02-14 changed daylight sensor images
2012-02-14 increased daylight threshold to sit new photoresistor mounting arrangement
